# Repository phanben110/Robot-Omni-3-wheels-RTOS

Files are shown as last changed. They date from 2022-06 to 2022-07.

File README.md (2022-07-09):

<h1 align="center">Robot Omni 3 Wheels RTOS</h1>

# Project Title

Vectoring code for a three wheel omni chassis written for Arduino Microcontroller.   
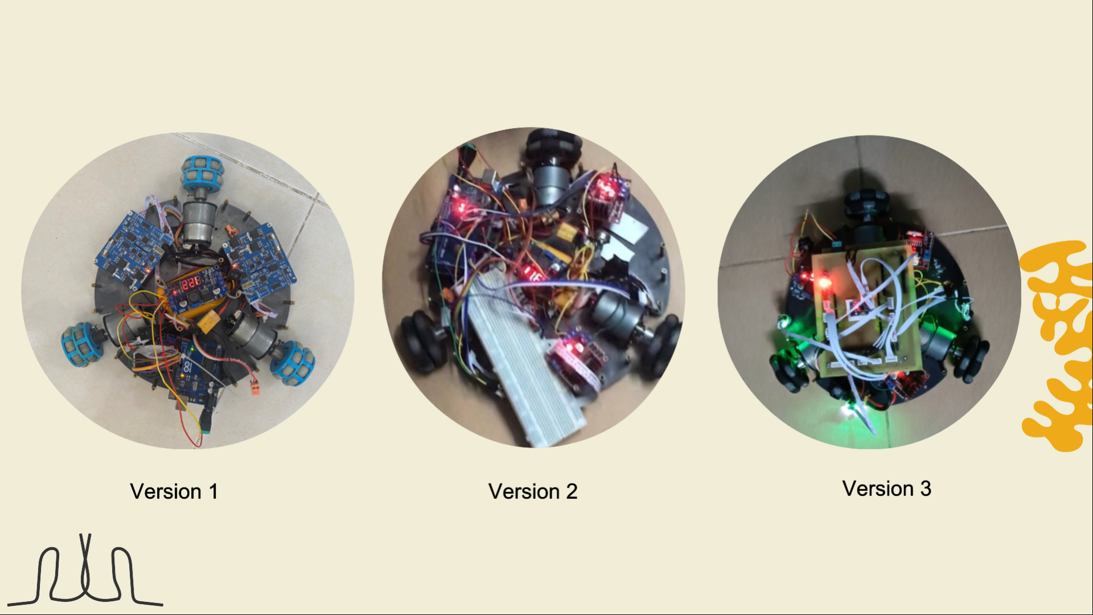
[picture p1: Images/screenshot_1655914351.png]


## DC Motor Speed Control
Motor speed control using encoders. Encoder are connected to the hardware interrupt of the microcontroller(Arduino Mega). A timer using the timming interrupt service routine is used to measure the motor rotation speed. System Identification is performed to approximate the DC motors as 2nd order system. PID controller is implemented for speed control.<br/>

## Vectoring
X and Y vector (or Magnitude, Theta) are transformed to the three motor RPMs.
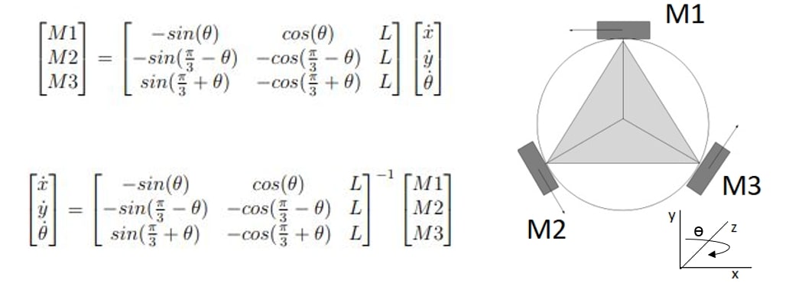
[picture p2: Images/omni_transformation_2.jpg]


## High Level Control
### 1. Control via ESP8266 blynk app: 
This functionality is added for the control of robot via ROS running your smart phone.

## Video demo
[Video Demo](https://www.youtube.com/watch?v=WiIC_UjOM_0) 

Contact us if you have any problem

## Authors

Contributors names and contact info

* [Phan Ben](https://www.facebook.com/benphan110) - Da Nang University of Technology - Email: phanben110@gmail.com
* [Dương Hoang Thanh Trúc](https://www.facebook.com/yul.duonqq) - Da Nang University of Technology
* [Nguyễn Hải Đức](https://www.facebook.com/duc.nguyenhai741) - Da Nang University of Technology
* [Phạm Thành Long](https://www.facebook.com/mrlong2k) - Da Nang University of Technology
* [Nguyễn Quốc Nhân](https://www.facebook.com/profile.php?id=100007475868554) - Da Nang University of Technology

## Acknowledgments

* [Tuning a PID Controller with Genetic Algorithms](https://www.youtube.com/watch?v=S5C_z1nVaSg&t=2s)
* [PID Speed and PID position](http://arduino.vn/result/5401-pid-speed-position-control)

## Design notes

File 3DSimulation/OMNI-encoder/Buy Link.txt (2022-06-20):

https://www.amazon.com/Diameter-Encoder-Different-Resolutions-2000PPR/dp/B01EWK93KQ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

https://www.amazon.com/Polyurethane-Position-Measuring-Mounting-1000PPR200mm/dp/B07H28681F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

https://www.amazon.com/Incremental-Optical-Encoder-Collector-8-24NPN/dp/B07SHDPF3W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

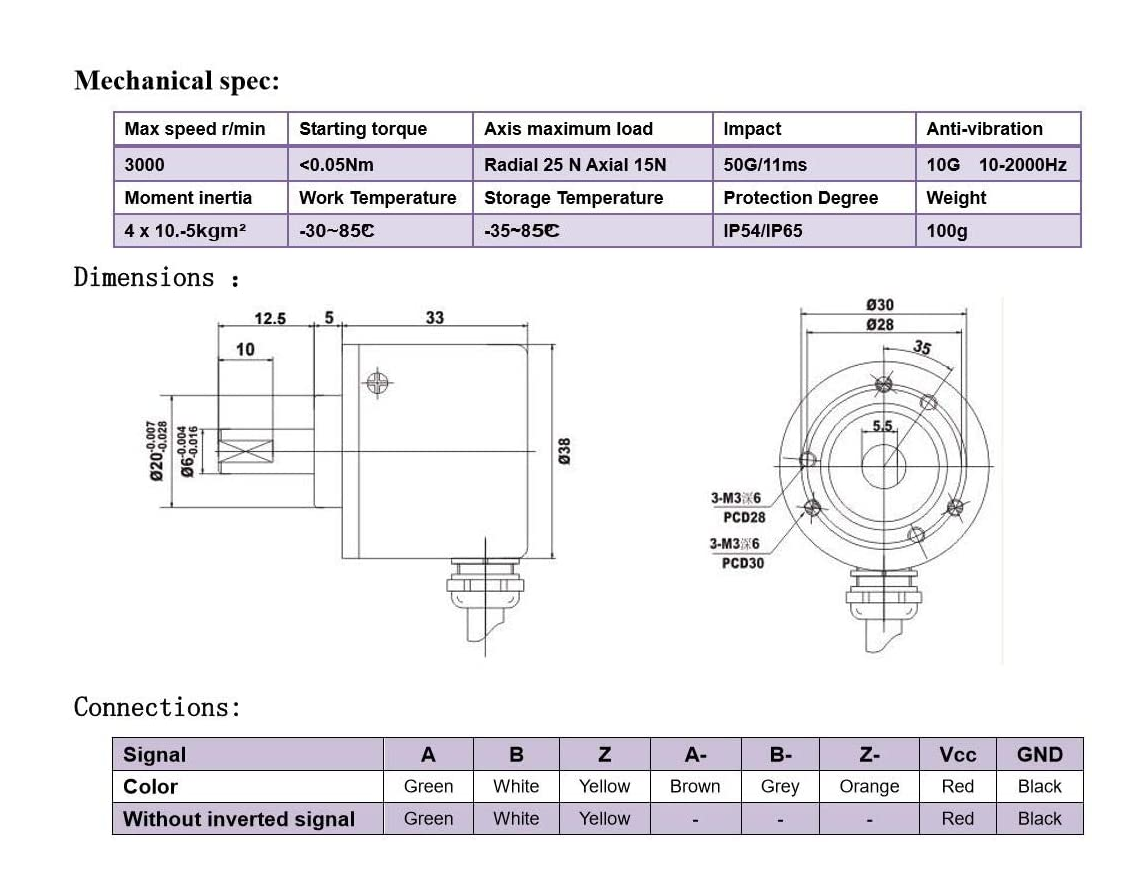
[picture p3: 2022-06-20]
3DSimulation/OMNI-encoder/38 mm OD, 6 mm Shaft, Incremental Optical Rotary Encoder Specs and Dimensions.PNG

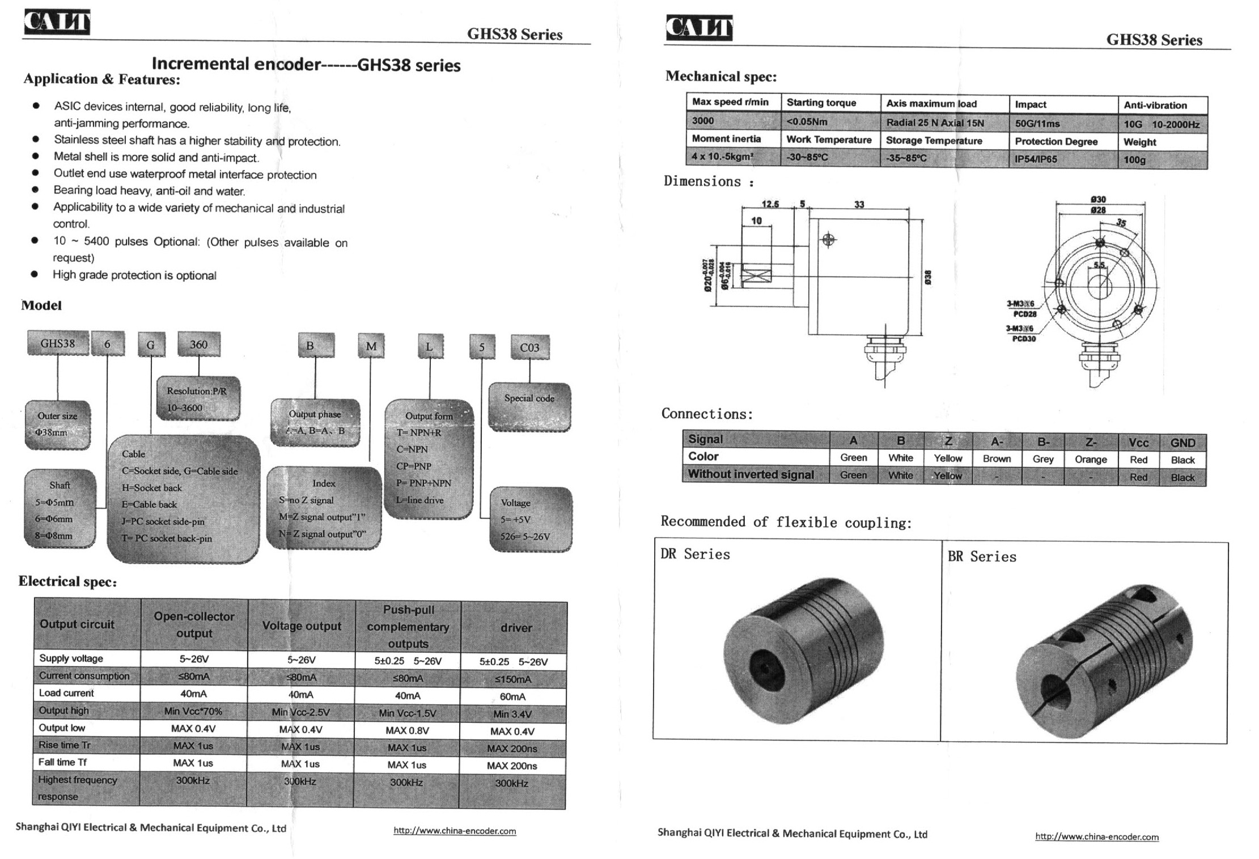
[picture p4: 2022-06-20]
3DSimulation/OMNI-encoder/GHS38 Series Encoder Specifications and Dimensions.jpg

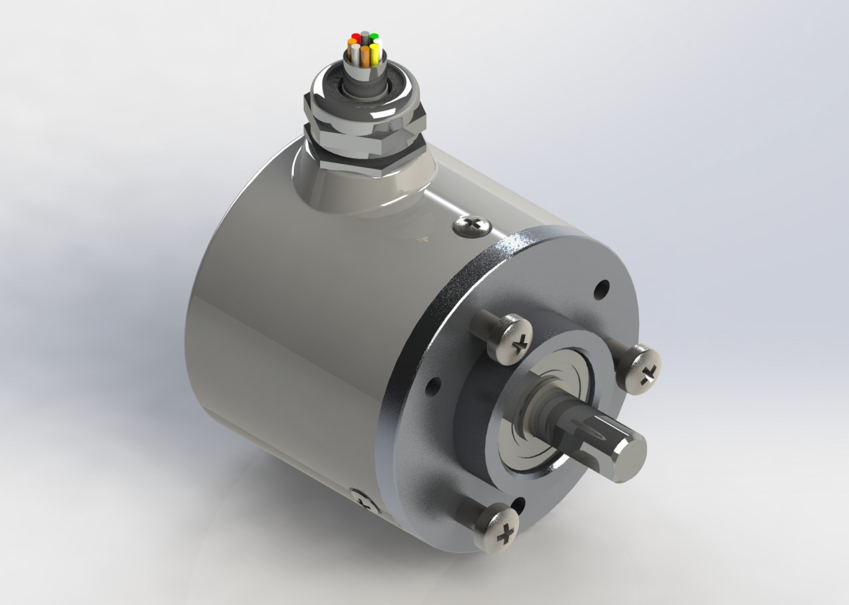
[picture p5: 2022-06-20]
3DSimulation/OMNI-encoder/38 mm OD, 6 mm Shaft, Incremental Optical Rotary Encoder.JPG

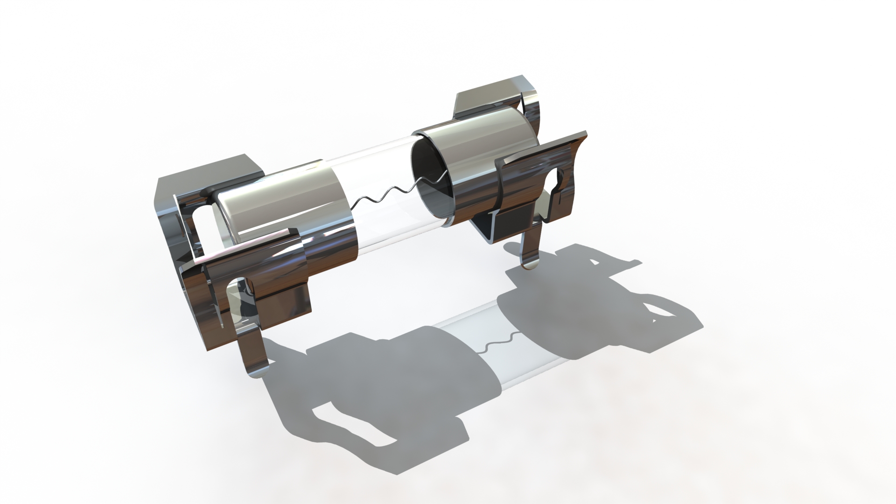
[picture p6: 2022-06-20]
3DSimulation/OMNI-DRIVER/5x15 Fuse with holder.JPG

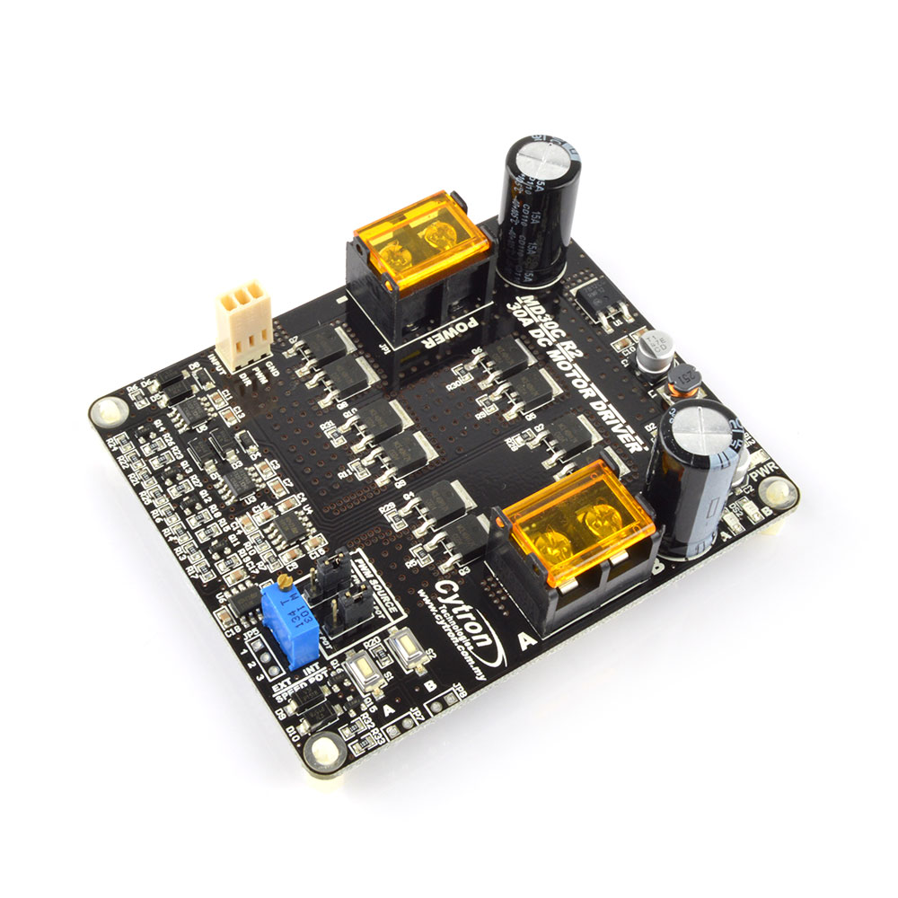
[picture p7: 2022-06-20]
3DSimulation/OMNI-DRIVER/Cytron 30A Driver.jpg

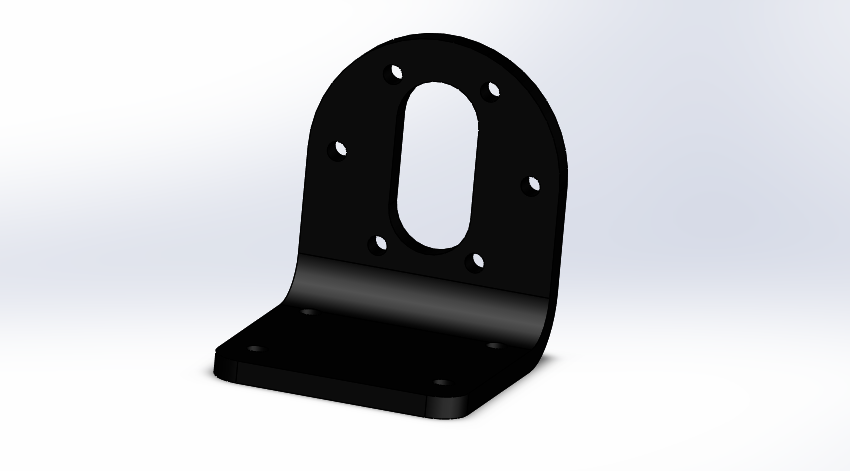
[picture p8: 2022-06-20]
3DSimulation/OMNI-GÁ ĐỘNG CƠ/Screenshot (52).png

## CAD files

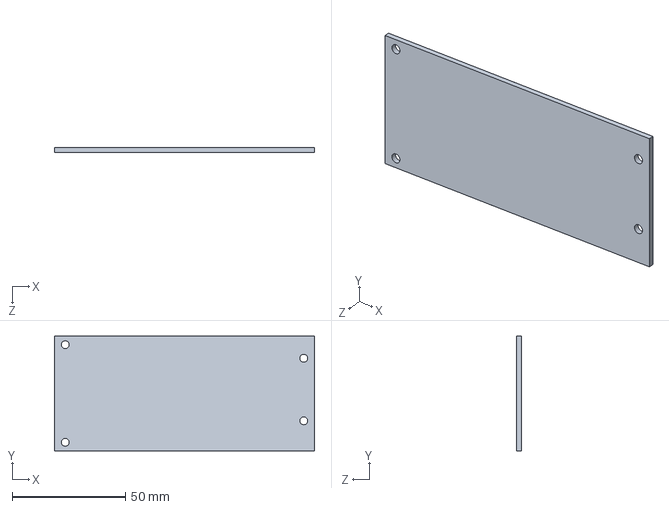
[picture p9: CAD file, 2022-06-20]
3DSimulation/OMNI-DRIVER/main board.SLDPRT
115.0 x 50.7 x 2.00 mm

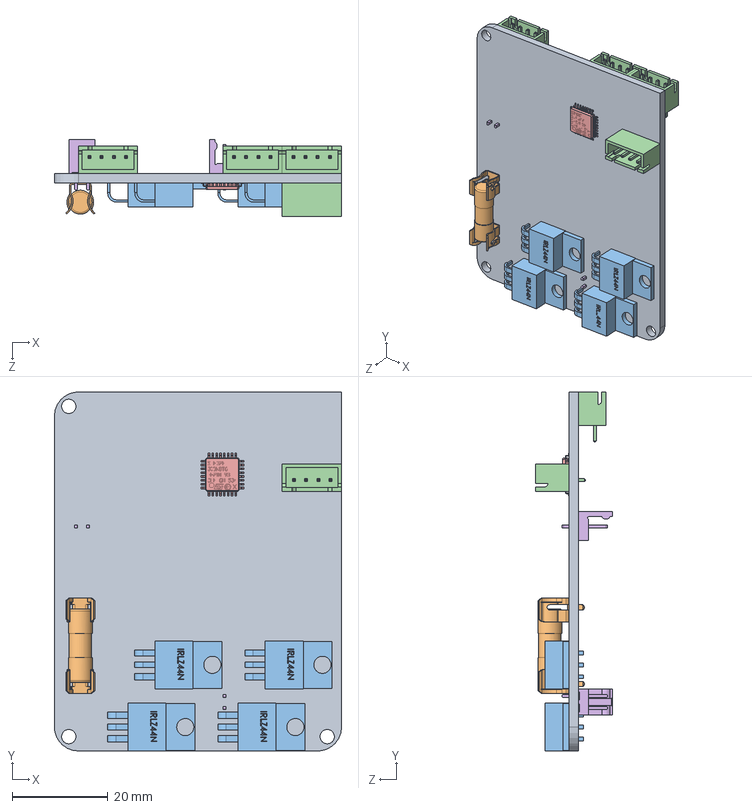
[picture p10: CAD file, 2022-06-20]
3DSimulation/OMNI-DRIVER/board driver SPKT.SLDASM
60.0 x 75.0 x 16.1 mm
board driver
5x15 Fuse with holder
ırlz44n x 4
JST XH 4 B4B-XH-A x 4
STM32_LQFP32
IL-G-2P-S3T2-SA x 2

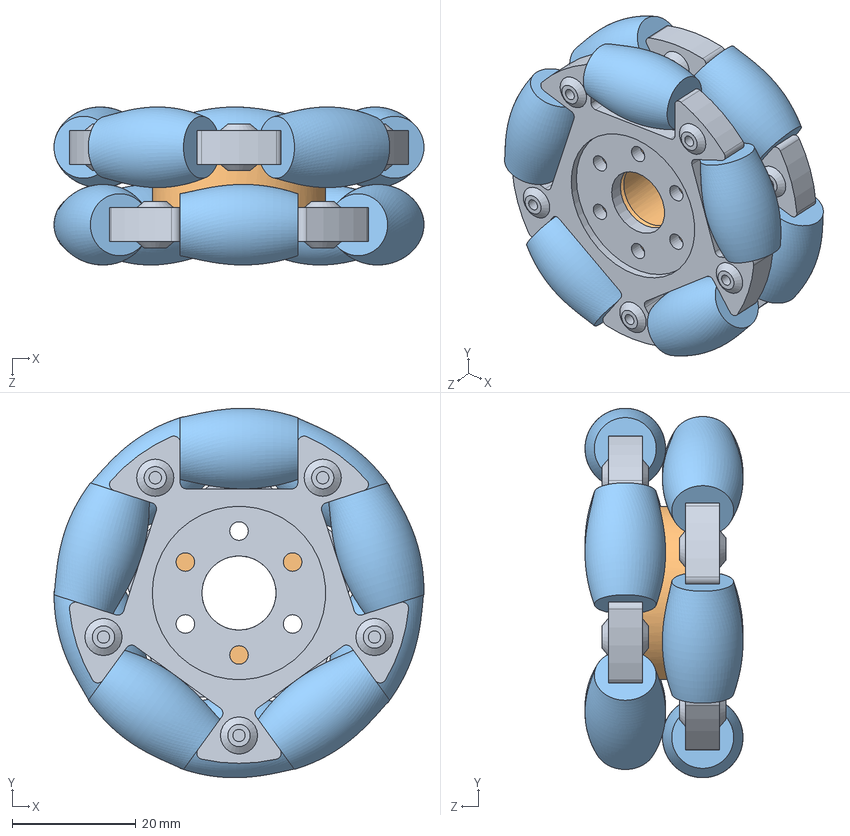
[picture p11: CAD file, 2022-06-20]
3DSimulation/OMNI-BÁNH NHÔM 60mm/Wheel/Wheel.SLDASM
59.7 x 59.6 x 25.5 mm
Alu_Base x 2
Middle_Plastic
Rubber x 10

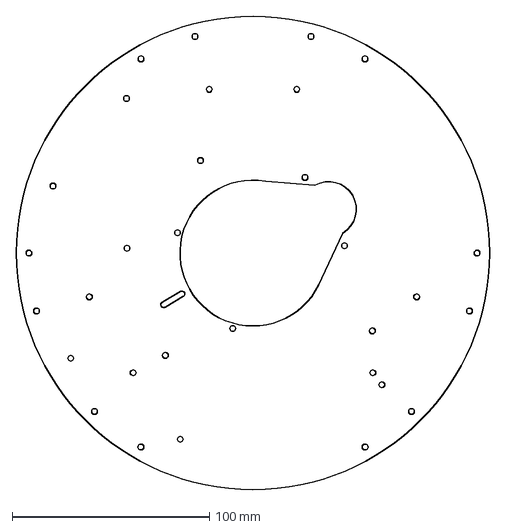
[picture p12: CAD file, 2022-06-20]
3DSimulation/file cắt cnc/VERSION 2.95 (main)/khung robot ver 2.95 mat tren inox 2li.DXF
240.0 x 240.0 mm

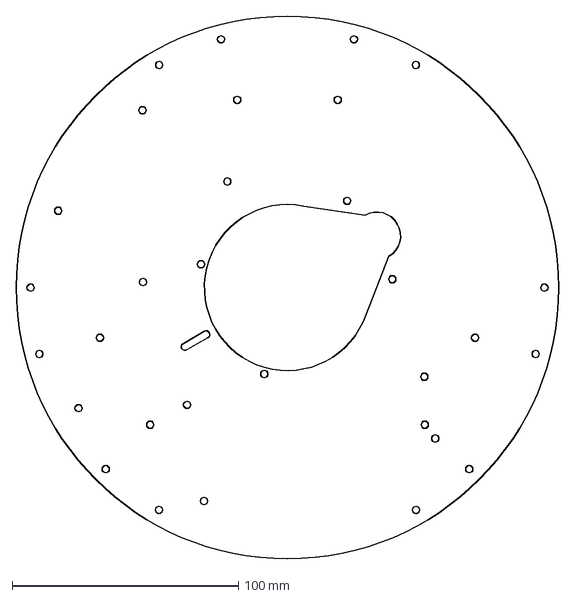
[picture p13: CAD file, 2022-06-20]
3DSimulation/file cắt cnc/VERSION 3.2/khung robot ver 3.2 mat tren.DXF
240.0 x 240.0 mm

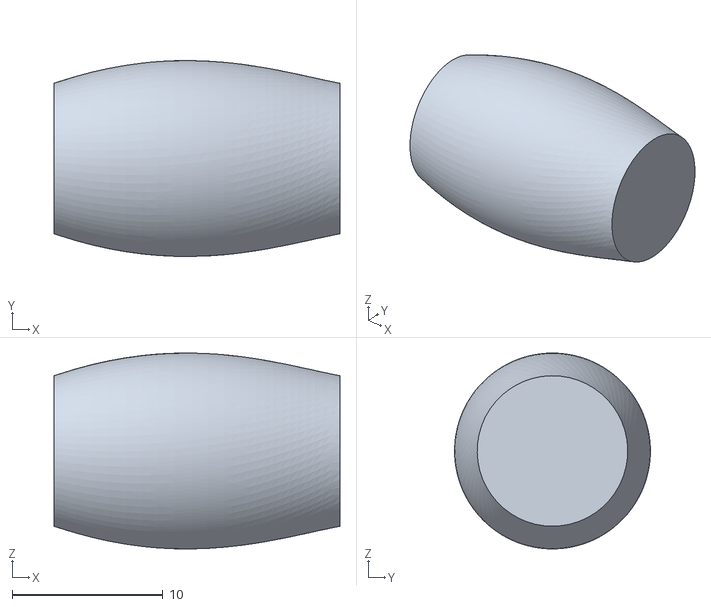
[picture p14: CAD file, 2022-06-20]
3DSimulation/OMNI-BÁNH NHÔM 60mm/Wheel/Wheel - Rubber-5.STL
19.0 x 13.0 x 13.0

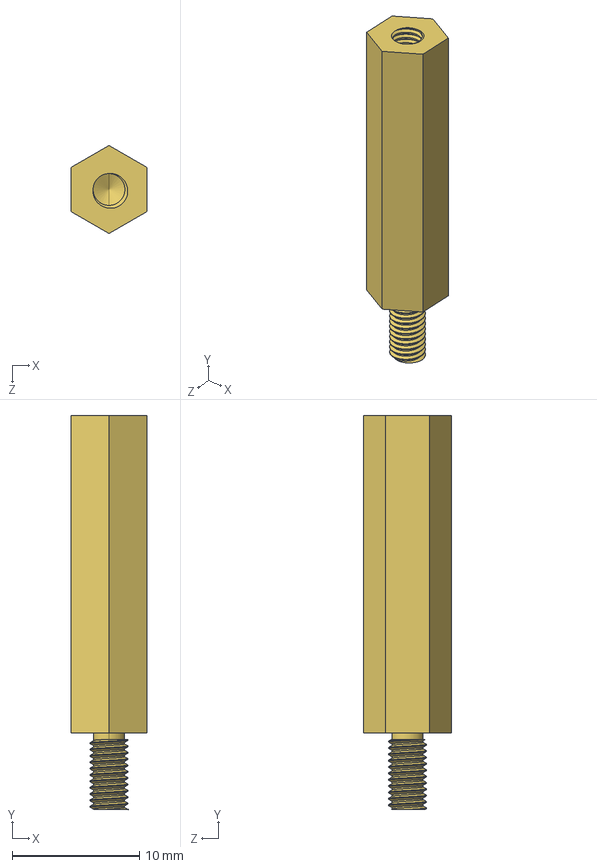
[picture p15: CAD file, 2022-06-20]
3DSimulation/OMNI-cọc đồng/cọc đồng 6mm/M3 x 6mm A-F x 25mm Hexagon Male-Female Threaded Pillar.STEP
6.00 x 31.0 x 6.93 mm

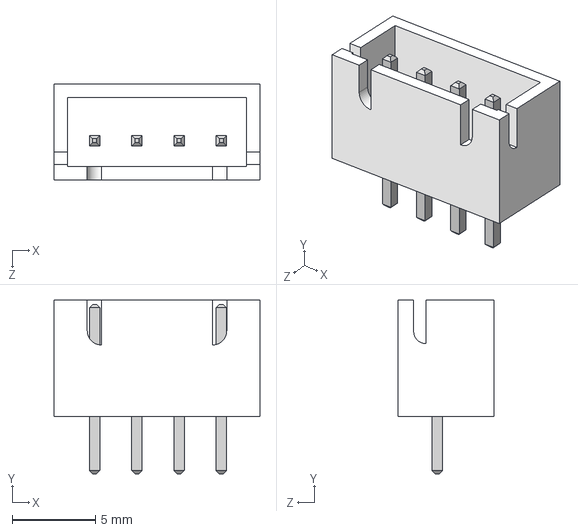
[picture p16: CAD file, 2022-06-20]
3DSimulation/OMNI-DRIVER/JST XH 4 B4B-XH-A.STEP
12.4 x 10.5 x 5.75 mm

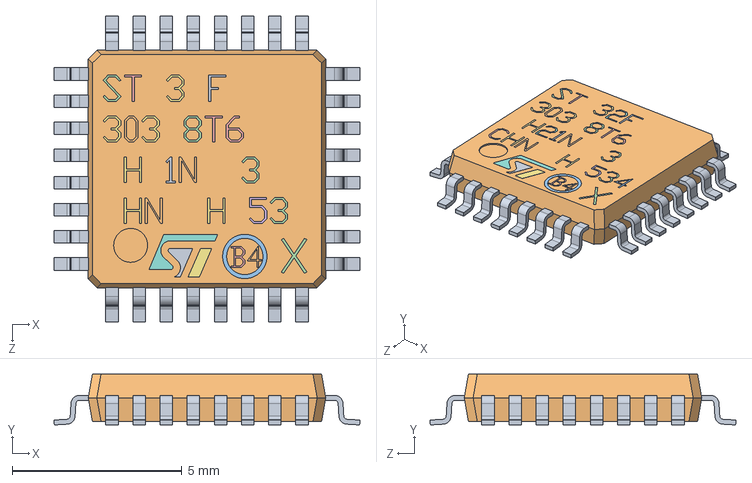
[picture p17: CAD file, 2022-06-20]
3DSimulation/OMNI-DRIVER/STEP/STM32_LQFP32_AP214.STEP
9.02 x 1.50 x 9.02 mm

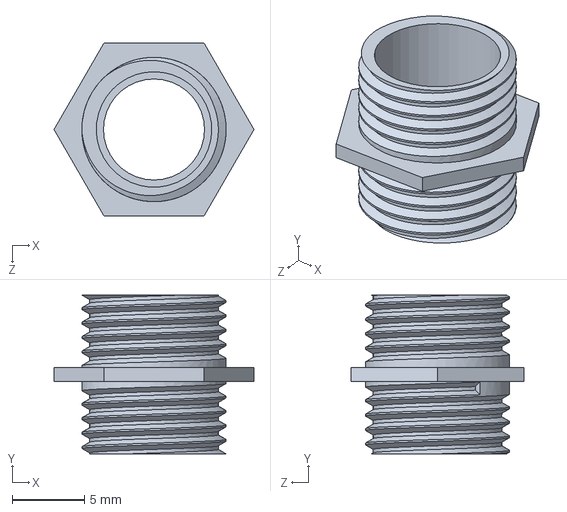
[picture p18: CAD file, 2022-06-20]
3DSimulation/OMNI-encoder/Cable Gland Coupling Nut, 38 mm OD, 6 mm Shaft, Incremental Optical Rotary Encoder.SLDPRT
13.9 x 11.0 x 12.0 mm

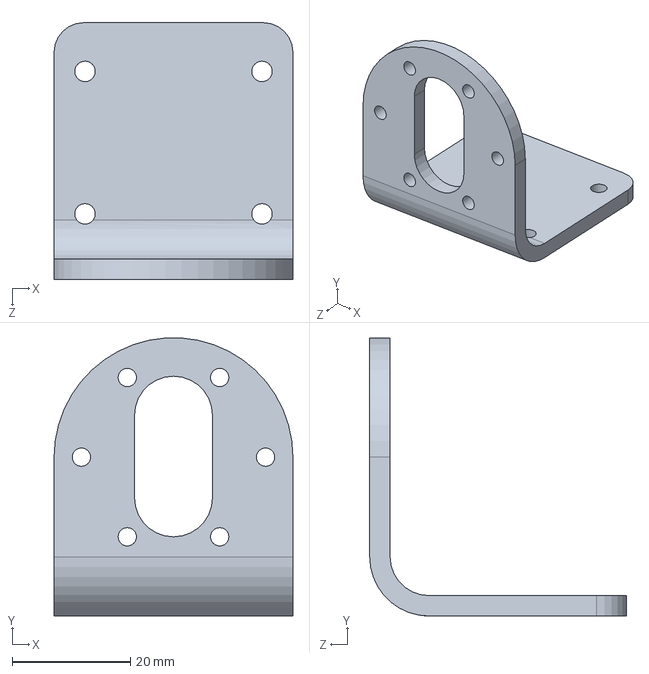
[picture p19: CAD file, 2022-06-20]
3DSimulation/OMNI-GÁ ĐỘNG CƠ/JGB37-520 12 v metal geared motor bracket.SLDPRT
40.3 x 47.0 x 43.3 mm

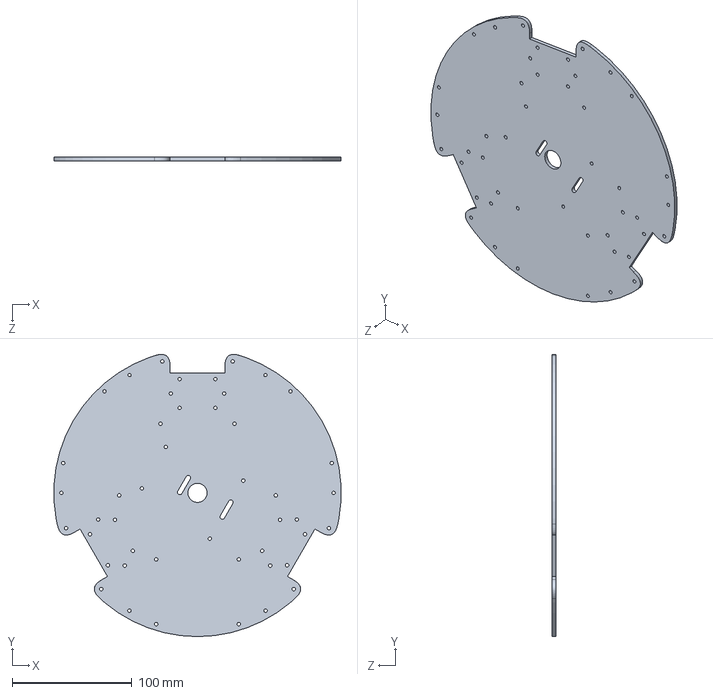
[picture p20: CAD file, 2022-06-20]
3DSimulation/OMNI-KHUNG ROBOT/khung robot ver2 co the chinh sua.SLDPRT
239.6 x 235.6 x 3.00 mm

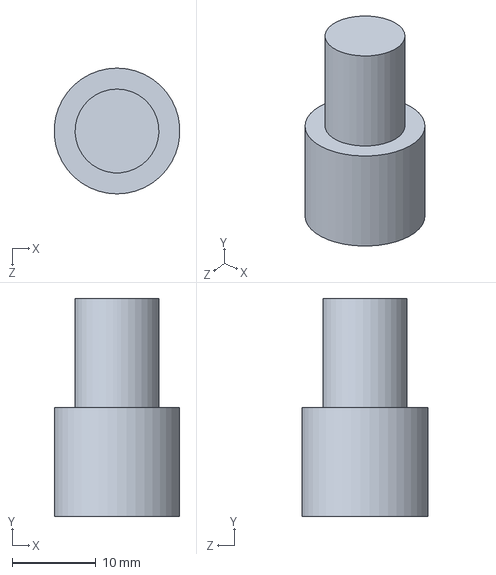
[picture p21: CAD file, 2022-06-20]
3DSimulation/OMNI-KHỚP NỐI TRỤC ĐỘNG CƠ/khớp nối thẳng.SLDPRT
15.0 x 26.0 x 15.0 mm

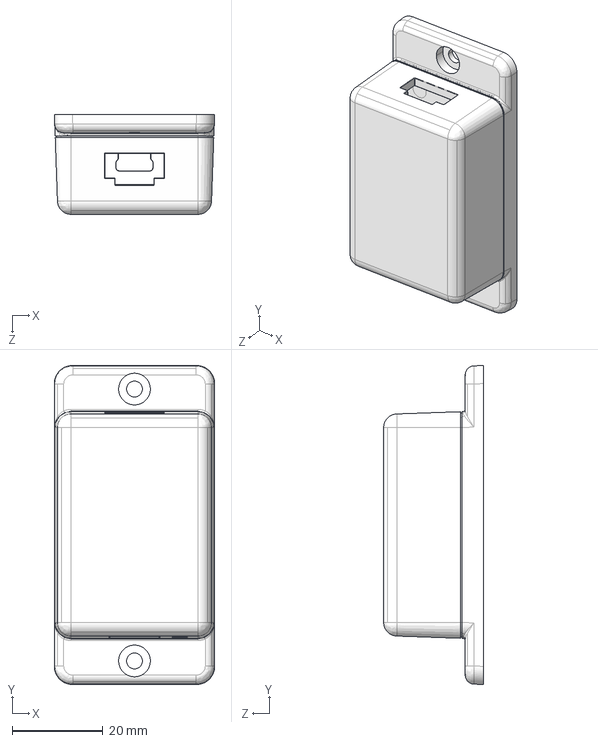
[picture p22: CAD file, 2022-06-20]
3DSimulation/OMNI-la bàn/ChipRobotics_IMU.STEP
35.4 x 70.4 x 22.0 mm

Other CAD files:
3DSimulation/OMNI-LIDAR/6.Lidar.SLDPRT
3DSimulation/OMNI-pin lipo/lipo-8-5-3cm.SLDPRT
3DSimulation/OMNI-raspberry 4/raspberry pi 4/Raspberry Pi 4 B.STEP
3DSimulation/OMNI-ĐỘNG CƠ/diaencoder.SLDPRT
3DSimulation/OMNI-BÁNH NHÔM 60mm/Wheel/Alu_Base.SLDPRT
3DSimulation/OMNI-BÁNH NHÔM 60mm/Wheel/Middle_Plastic.SLDPRT
3DSimulation/OMNI-BÁNH NHÔM 60mm/Wheel/Rubber.SLDPRT
3DSimulation/OMNI-BÁNH NHÔM 60mm/Wheel/Wheel - Alu_Base-1.STL
3DSimulation/OMNI-BÁNH NHÔM 60mm/Wheel/Wheel - Alu_Base-2.STL
3DSimulation/OMNI-BÁNH NHÔM 60mm/Wheel/Wheel - Middle_Plastic-1.STL
3DSimulation/OMNI-BÁNH NHÔM 60mm/Wheel/Wheel - Rubber-1.STL
3DSimulation/OMNI-BÁNH NHÔM 60mm/Wheel/Wheel - Rubber-10.STL
3DSimulation/OMNI-BÁNH NHÔM 60mm/Wheel/Wheel - Rubber-2.STL
3DSimulation/OMNI-BÁNH NHÔM 60mm/Wheel/Wheel - Rubber-3.STL
3DSimulation/OMNI-BÁNH NHÔM 60mm/Wheel/Wheel - Rubber-4.STL
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

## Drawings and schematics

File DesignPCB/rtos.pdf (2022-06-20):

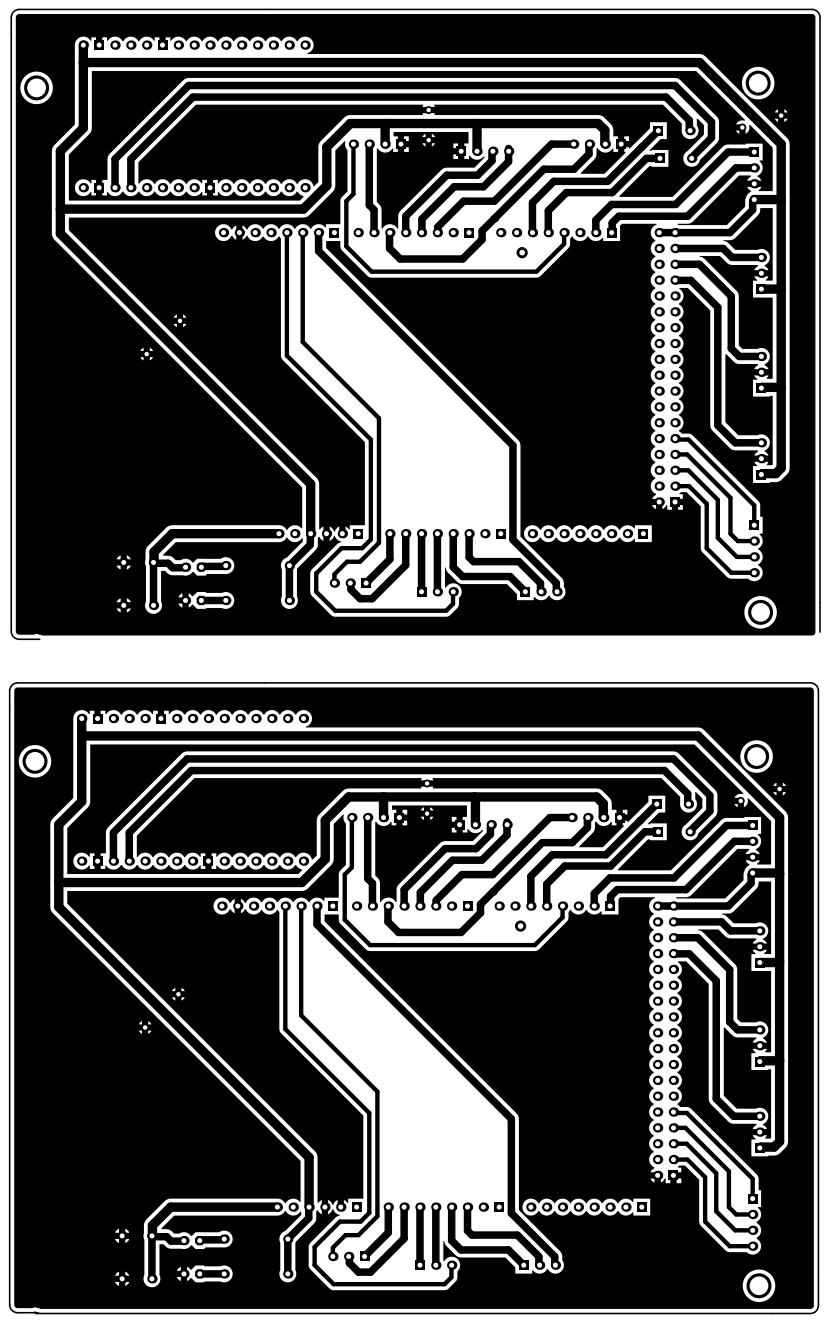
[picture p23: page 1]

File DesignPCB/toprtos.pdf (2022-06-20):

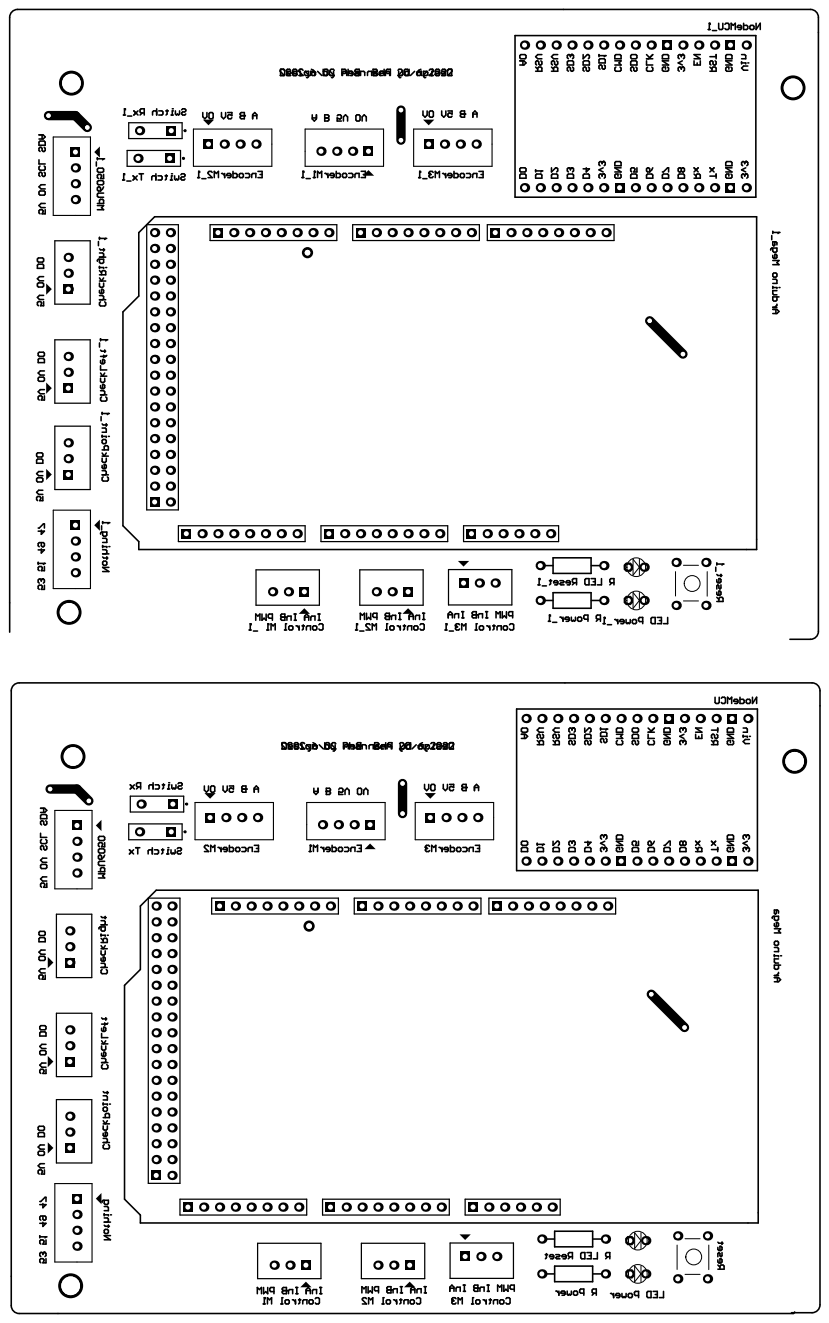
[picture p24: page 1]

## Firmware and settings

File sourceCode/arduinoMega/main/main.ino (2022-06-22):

#include <Arduino.h>
#include <Arduino_FreeRTOS.h>
#include <Wire.h>
#include "PinChangeInt.h"
#include "PID_v1.h"
#include "mpu6050.h"
#include "motor.h"
#include "vectoring.h"
#include "definePin.h"

MPU6050 mpu6050;
const bool DEBUG = false ;
const int SPEED = 80;
double kp = 5 , ki = 1 , kd = 0.01 ;  // modify kp, ki and kd for optimal performance
double input1 = 0, output1 = 0, setpoint1 = 0,  kp1 = 5 , ki1 = 1 , kd1 = 0.01 ;
double input2 = 0, output2 = 0, setpoint2 = 0,  kp2 = 5 , ki2 = 1 , kd2 = 0.01;
double input3 = 0, output3 = 0, setpoint3 = 0,  kp3 = 5 , ki3 = 1 , kd3 = 0.01;
double denta1 = 0, denta2 = 0, denta3 = 0;
float denta[3], rot;
long temp;
bool Enable = 0, isSent = 0, isSent2 = 0;
int zone = 0 ;

volatile long encoderPos1 = 0;
volatile long encoderPos2 = 0;
volatile long encoderPos3 = 0;

PID M1PID(&input1, &output1, &setpoint1, kp1, ki1, kd1, DIRECT);  // if motor will only run at full speed try 'REVERSE' instead of 'DIRECT'
PID M2PID(&input2, &output2, &setpoint2, kp2, ki2, kd2, DIRECT);
PID M3PID(&input3, &output3, &setpoint3, kp3, ki3, kd3, DIRECT);

void TaskLive( void *pvParameters );
//void TaskUART(void *pvParameters);

int v1;
int v2;
int v3;
float vel_x;
float vel_y;
float theta;
int magnitude , countNPN ;
TaskHandle_t Task_Handle1;
//TaskHandle_t Task_Handle2;

void setup() {
  Serial2.begin(115200);
  Serial.begin(115200);
  pinMode(encoder1PinA, INPUT_PULLUP);                  // quadrature encoder input A
  pinMode(encoder1PinB, INPUT_PULLUP);                  // quadrature encoder input B
  pinMode(encoder2PinA, INPUT_PULLUP);                  // quadrature encoder input A
  pinMode(encoder2PinB, INPUT_PULLUP);                  // quadrature encoder input B
  pinMode(encoder3PinA, INPUT_PULLUP);                  // quadrature encoder input A
  pinMode(encoder3PinB, INPUT_PULLUP);                  // quadrature encoder input B
  pinMode(checkLeft, INPUT);
  pinMode(checkNPN, INPUT);
  pinMode(photoRes, INPUT);
  // update encoder position
  attachInterrupt(digitalPinToInterrupt(3), encoder1, FALLING);
  attachInterrupt(digitalPinToInterrupt(2), encoder2, FALLING);
  attachInterrupt(digitalPinToInterrupt(18), encoder3, FALLING);
  // set timer 31KHz to read encoder
  TCCR1B = (TCCR1B & 0b11111000) | 0x01;

  //PID M1 intializations
  M1PID.SetMode(AUTOMATIC);
  M1PID.SetSampleTime(1);
  M1PID.SetOutputLimits(-255, 255);

  //PID M1 intializations
  M2PID.SetMode(AUTOMATIC);
  M2PID.SetSampleTime(1);
  M2PID.SetOutputLimits(-255, 255);

  //PID M1 intializations
  M3PID.SetMode(AUTOMATIC);
  M3PID.SetSampleTime(1);
  M3PID.SetOutputLimits(-255, 255);

  //create task in RTOS
  xTaskCreate(TaskLive, "Task1", 256, NULL, 2, &Task_Handle1);
  //xTaskCreate(TaskUART, "Task2", 256, NULL, 1, &Task_Handle2);
  vTaskStartScheduler();
}

void loop() {}
void TaskLive(void *pvParameters)
{
  // Code test run robot Omni 3 wheels
  mpu6050_begin();
  float increase = 30;
  float ROT = 3;
  float a = 0.5;
  while (1)
  {
    if (increase <= SPEED ) // tăng tốc dần lên increase
    {
      increase += 0.25 ;
    }
    float current_dir = mpu6050_yaw();
    base1(magnitude, theta, rot, denta);
    countNPN = LeftRight();
    Serial.println(countNPN);
    // Receive signal control from UART with ESP8266
    int Enable = receive();
    if ( Enable == 0)
    {
      magnitude = 0 ;
      theta = 0;
      rot = 0 ;
      zone = 0;
    }
    else if ( Enable == 1 && countNPN < 1)    // Go Straight
    {
      /*
        Theta = -90 : Chạy thẳng,
        Theta = -180 :  Rẻ phải ( chạy ngang ) ,
        Theta = 0 : Rẻ trái,
      */
      magnitude = increase ;
      theta = -90;
      rot = 2   * current_dir; // Hệ số điều chỉnh
    }
    else if (Enable == 1 && countNPN == 1 )   //Turn Right
    {
      magnitude = 35;
      theta = 0;
      rot =   0.8 * current_dir;
      Serial2.println(3);
    }
    else if (Enable == 2 && countNPN == 1 )  //Turn Left
    {
      magnitude = 35;
      theta = -180;
      rot =   0.8 * current_dir;
      Serial2.println(3);
    }
    else if (countNPN == 2)   //Stop
    {
      magnitude = 0 ;
      theta = 0;
      rot = 0;
      Serial2.println(5);
    }
    if ( DEBUG )
    {
      Serial.print(" -- Angle : ") ;
      Serial.print(current_dir) ;
      Serial.print(" --- denta1: ") ;
      Serial.print(denta[0]) ;
      Serial.print(" denta2: ") ;
      Serial.print(denta[1]) ;
      Serial.print(" denta3: ") ;
      Serial.println(denta[2]) ;
    }

    setpoint1 += denta[0];
    setpoint2 += denta[1];
    setpoint3 += denta[2];

    input1 = encoderPos1 ;
    input2 = encoderPos2 ;
    input3 = encoderPos3 ;

    M1PID.Compute();
    M2PID.Compute();
    M3PID.Compute();

    M1(output1);
    M2(output2);
    M3(output3);
    vTaskDelay(1);
  }
}
//void TaskUART(void *pvParameters)
//{
//  (void) pvParameters;
//  unsigned int Frequency = 1;
//  TickType_t xLastWakeTime;
//  xLastWakeTime = xTaskGetTickCount();
//  while (1)
//  {
//    Serial.println("Task2");
//    receive();
//  }
//
//  //vTaskDelayUntil(&xLastWakeTime, Frequency);
//  vTaskDelay(100);
//}

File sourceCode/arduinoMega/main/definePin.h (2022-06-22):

//Define pin arduino Mega 6050
//motor1 intializations
#define inAPin1  A4
#define inBPin1  A5
#define PWMPin1  9
//motor2 intializations
#define inAPin2  A2
#define inBPin2  A3
#define PWMPin2  11
//motor3 intializations
#define inAPin3  A0
#define inBPin3  A1
#define PWMPin3  10

//Encoder1 for motor1 intializations
#define encoder1PinA  3
#define encoder1PinB  4
//Encoder1 for motor1 intializations
#define encoder2PinA  2
#define encoder2PinB  5
//Encoder1 for motor1 intializations
#define encoder3PinA  18    //motor 3
#define encoder3PinB  6
//Sensor
#define checkLeft 25 // checkpoint (zone)
#define checkNPN 27 //check right
#define photoRes 23 // checkLeft

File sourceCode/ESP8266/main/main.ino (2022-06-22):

#include <Arduino.h>
#include <SoftwareSerial.h>
#define BLYNK_PRINT Serial

#include <ESP8266WiFi.h>
#include <BlynkSimpleEsp8266.h>

char auth[] = "FslaEJTx3tXexTyrobtWyQ7HfnUS4H5t";

//char ssid[] = "Nang Nhung";
//char pass[] = "0989122125";
//char ssid[] = "WIGIGI-2.4G";
//char pass[] = "cuocsongma";
char ssid[] = "HappiRoomPlus";
char pass[] = "Dat160420";
int pinValue;
int pinValue2 ;

WidgetLED led1(V3);
WidgetLED led2(V4);
WidgetLED led3(V5);
WidgetLED led4(V6);
WidgetLED led5(V7);

String zone = "0";
char msg[20] = {0};

const int tx = 4;
const int rx = 5;
SoftwareSerial mySerial(rx, tx);
BLYNK_WRITE(V1) // this command is listening when something is written to V1
{
  pinValue = param.asInt(); // assigning incoming value from pin V1 to a variable


  //Serial.print("V1 button value is: "); // printing value to serial monitor
  //Serial.println(pinValue);
}

BLYNK_WRITE(V2) // this command is listening when something is written to V1
{
  pinValue2 = param.asInt(); // assigning incoming value from pin V1 to a variable


  //Serial.print("V1 button value is: "); // printing value to serial monitor
  //Serial.println(pinValue);
}

void setup()
{
  // Debug console
  Serial.begin(115200);
  mySerial.begin(9600);
  Blynk.begin(auth, ssid, pass);
  led1.off();
  led2.off();
  led3.off();
  led4.off();
  led5.off();
  //  lcd.print(0, 0, "Zone=0");
}

void loop()
{
  Blynk.run();
  if (pinValue == 1 && pinValue2 == 0 )
  {
    Serial.println(1);  // xem
    Blynk.virtualWrite(V2, 0);

    //mySerial.print("start");  // lenh xuong arduino
  }
  else if (pinValue == 0 && pinValue2 == 1 )
  {
    Serial.println(2);  // xem
    Blynk.virtualWrite(V1, 0);
    //mySerial.print("start");  // lenh xuong arduino
  }

  else if (pinValue == 0 && pinValue2 == 0)
  {
    Serial.println(0);
    led1.off();
    led2.off();
    led3.off();
    led4.off();
    led5.off();
    //mySerial.print("stop");
  }


  // UART from arduino
  //  if (mySerial.available())
  //  {
  //    zone = mySerial.readString();
  //    sprintf(msg, "Zone=%s ", zone);
  //    Serial.println(msg);
  //    lcd.print(0, 0, msg);
  //  }
  if (Serial.available())
  {
    zone = Serial.readStringUntil('\n');
    int checkPoint = zone.toInt();
    //Serial.println(checkPoint);
    if (checkPoint == 1 )
    {
      led1.on();
      led2.off();
      led3.off();
      led4.off();
      led5.off();
    }
    else if ( checkPoint == 2 )
    {
      led1.on();
      led2.on();
      led3.off();
      led4.off();
      led5.off();
    }
    else if ( checkPoint == 3 )
    {
      led1.on();
      led2.on();
      led3.on();
      led4.off();
      led5.off();
    }
    else if ( checkPoint == 4 )
    {
      led1.on();
      led2.on();
      led3.on();
      led4.on();
      led5.off();
    }
    else if ( checkPoint == 5 )
    {
      led1.on();
      led2.on();
      led3.on();
      led4.on();
      led5.on();
    }
  }
  delay(100);
}

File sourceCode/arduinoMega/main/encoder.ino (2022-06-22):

// pulse and direction, direct port reading to save cycles
void encoder1()
{
  if (digitalRead(encoder1PinB) == HIGH)   encoderPos1++;
  if (digitalRead(encoder1PinB) == LOW)   encoderPos1--;
  if ( DEBUG )
  {
    Serial.print("Encoder1");
    Serial.println(encoderPos1);
  }

}
// pulse and direction, direct port reading to save cycles
void encoder2()  {
  if (digitalRead(encoder2PinB) == HIGH)   encoderPos2++;
  if (digitalRead(encoder2PinB) == LOW)   encoderPos2--;
  if ( DEBUG )
  {
    Serial.print("Encoder2");
    Serial.println(encoderPos2);
  }
}
// pulse and direction, direct port reading to save cycles
void encoder3()  {

  if (digitalRead(encoder3PinB) == HIGH)   encoderPos3++;
  if (digitalRead(encoder3PinB) == LOW)   encoderPos3--;
  if ( DEBUG )
  {
    Serial.print("Encoder3");
    Serial.println(encoderPos3);
  }

}

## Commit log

2022-06-20 update full project
    [38 mm OD, 6 mm Shaft, Incremental Optical Rotary Encoder.SLDASM, 38 mm OD, 6 mm Shaft, Incremental Optical Rotary Encoder.STEP, 38 mm OD, 6 mm Shaft, Increment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]
2022-06-22 update UART task
